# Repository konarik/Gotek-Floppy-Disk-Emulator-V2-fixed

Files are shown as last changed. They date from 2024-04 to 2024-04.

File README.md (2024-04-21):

Fixed PCB from original [Gotek-Floppy-Disk-Emulator-V2](https://github.com/RichardRozehnal/Gotek-Floppy-Disk-Emulator-V2):
* Add PCB edge cut for IDC 34-pin cable keying
* Change Buzzer type from Active to Passive (single click on drive motor step)
* Change "Buzzer_12x9.5RM7.6" footprint to "Buzzer_12x9.5RM6.5"

New modifications in V2.1:
* SMD Crystal
* 2nd SMD diode
* electrolytic capacitor replaced with 10uF MLCC
* decoupling capacitors moved close to the MCU
* added mounting holes
* generated production files for JLCPCB except through hole parts and 8bit SMD switch

# Gotek Floppy Disk Emulator V2

Gotek Floppy Disk Emulator V2

Emulátor disketové mechaniky starých počítačů a různých zařízení. Software se do počítače nahrává z obrazu originálního disku (např. ADF pro Amigu), který je uložen na USB flash disku. Tato verze hardwaru využívá firmware [FlashFloppy](https://github.com/keirf/FlashFloppy/wiki), který přidává spoustu nových funkcí a vylepšení oproti standardnímu Goteku. Na uvedém odkazu tvůrce, najdete detailní popisy všech funkcí a nastavení a také nejnovější firmware.

## Seznam součástek

| **Reference** | **Value** | **Qty**  |
| --- | --- | :----: |
| <sup>BZ1 </sup>| <sup>5V Passive Buzzer 12mm </sup>| <sup> 1 </sup> |
| <sup>C1,C2,C4,C7,C8,C9,C10,C12 </sup>| <sup>100nF </sup>| <sup> 8 </sup> |
| <sup>C3,C11 </sup>| <sup>10uF </sup>| <sup> 2 </sup> |
| <sup>C5,C6 </sup>| <sup>22pF </sup>| <sup> 2 </sup> |
| <sup>C13 </sup>| <sup>10uF/16V </sup>| <sup> 1 </sup> |
| <sup>D1,D101 </sup>| <sup>LED Green </sup>| <sup> 2 </sup> |
| <sup>D2 </sup>| <sup>1N4148 </sup>| <sup> 1 </sup> |
| <sup>H1 </sup>| <sup>Hole1 </sup>| <sup> 1 </sup> |
| <sup>H2 </sup>| <sup>Hole2 </sup>| <sup> 1 </sup> |
| <sup>H3 </sup>| <sup>Hole3 </sup>| <sup> 1 </sup> |
| <sup>H4 </sup>| <sup>Hole4 </sup>| <sup> 1 </sup> |
| <sup>J1 </sup>| <sup>Power Connector </sup>| <sup> 1 </sup> |
| <sup>J2 </sup>| <sup>OLED Display 0.91" Modul </sup>| <sup> 1 </sup> |
| <sup>J3 </sup>| <sup>USB_A </sup>| <sup> 1 </sup> |
| <sup>J5 </sup>| <sup>Programming Connector </sup>| <sup> 1 </sup> |
| <sup>J6 </sup>| <sup>Floppy Data Connector </sup>| <sup> 1 </sup> |
| <sup>Q1 </sup>| <sup>MMBT2222 </sup>| <sup> 1 </sup> |
| <sup>Q2,Q3,Q4,Q5,Q6,Q7 </sup>| <sup>BSS123 </sup>| <sup> 6 </sup> |
| <sup>R1 </sup>| <sup>4K7 </sup>| <sup> 1 </sup> |
| <sup>R2,R3,R7,R8,R9,R10,R11,R12,R13,R14,R15,R16,R17,R18,R19,R20,R21,R22,R23,R24,R25,R26,R101,R102 </sup> | <sup>1K </sup> | <sup>24 </sup> |
| <sup>R4,R27 </sup>| <sup>10K </sup> | <sup> 2 </sup> |
| <sup>R5,R6 </sup>| <sup>22R </sup> | <sup> 2 </sup> |
| <sup>SW1 </sup>| <sup>KY040 Rotary Encoder </sup> | <sup> 1 </sup> |
| <sup>SW2 </sup>| <sup>DIP Switch </sup> | <sup> 1 </sup> |
| <sup>U1 </sup>| <sup>AMS1117-3.3 </sup> | <sup> 1 </sup> |
| <sup>U2 </sup>| <sup>STM32F105RBTx </sup> | <sup> 1 </sup> |
| <sup>U3 </sup>| <sup>STMPS2141 </sup> | <sup> 1 </sup> |
| <sup>U4 </sup>| <sup>74HCT04 </sup> | <sup> 1 </sup> |
| <sup>Y1 </sup>| <sup>8MHz </sup> | <sup> 1 </sup> |

## Oživení

### Programování mikrokontroléru pomocí ST-Link V2

1. stáhněte si a nainstalujte flashovací program STM32-ST-Link Utility na webu [st.com](https://www.st.com/en/development-tools/stsw-link004.html).
2. propojte ST-Link V2 a Gotek V2 vývody SWCLK, SWDIO, GND a +3.3V
3. připojte ST-Link V2 k PC a spusťte flashovací program
4. připojte se na MCU přes menu Target/Connect
5. přes menu File/Open File vyberte soubor FF_Gotek-v3.20.hex (nebo jiný, který chcete nahrát do MCU)
6. spusťte flashování přes menu Target/Program & Verify a Start

### Nastavení DIP přepínače SW2

Pro Amigu, Atari ST a další počítače je nastavení:

| **sig** | **zap/vyp** | **funkce** |
| :-----: | :---: | --- |
| DC1 | OFF | |
| DC2 | ON | |
| J5 | OFF | |
| JC | OFF | |
| JB | ON | zapnutí/vypnutí emulace zvuku mechaniky |
| S0 | ON | |
| S1 | OFF | |

### Příprava USB flash disku a základní operace

1. USB flash disk naformátujte na FAT32 a nahrajte na něj obrazy disků, které budete chtít spouštět, např. ADF pro Amigu
2. připojte Gotek V2 s vloženým USB flash diskem k Amize (místo interního floppy disku), napájecí konektor je dobré před zapojením změřit, abyste do Goteku V2 nepustili 12V místo 5V, kvůli obrácení konektoru!
3. zapněte Amigu, na displeji se zobrazí první z podporovaných souborů, které jste nahráli a rotačním enkodérem mezi nima vybíráte
4. když najedete na soubor a počkáte 2s, tak se automaticky spustí (vloží do floppy mechaniky). Toto je možné v nastavení změnit, aby se automaticky nespouštěl. Potom bude pro vložení do mechaniky nutné stisknout rotační enkodér.
5. pokud chcete změnit orientaci posuvu v souborech (otáčení enkodéru doprava/doleva posouvat soubory nahoru/dolů), je to možné změnit v nastavení.
6. pokud se výběr souborů posune o jednu položku až při dvou nebo čtyřech krocích otočení enkodérem, je možné toto také upravit v nastavení

### Nastavení firmware

1. Gotek V2 funguje s defaultním nastavením i bez konfiguračního souboru
2. pokud však chcete určitou konfiguci změnit, vytvořte na USB flash disku adresář FF a do něj nahrajte konfigurační soubor FF.CFG
3. zrušení automatického spouštění souboru: autoselect-file-secs = 0
4. zrušení automatického vybrání adresáře: autoselect-folder-secs = 0
5. změna orientace posuvu v souborech: rotary = reverse
6. změna kroků enkodéru: rotary = half
7. je možné vybrat i více nastavení najednou, např.: rotary = reverse,half

## Další fotky (vzorky, úprava na BOT straně již není potřeba)

Gotek_V2_PCB_Top
Gotek_V2_PCB_Bot
Gotek_V2_PCB_Bot_osazeny

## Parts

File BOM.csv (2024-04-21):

Reference | Value | Datasheet | Footprint | Qty | DNP
BZ1 | 5V Passive Buzzer 12mm | ~ | Gotek_Floppy_Disk_Emulator_V2:Buzzer_12x9.5RM6.5 | 1
C1,C2,C4,C7,C8,C9,C10,C12 | 100nF | ~ | Capacitor_SMD:C_1206_3216Metric | 8
C3,C11 | 10uF | ~ | Capacitor_SMD:C_1206_3216Metric | 2
C5,C6 | 22pF | ~ | Capacitor_SMD:C_0402_1005Metric | 2
C13 | 10uF/16V | ~ | Capacitor_SMD:C_1206_3216Metric | 1
D1,D101 | LED Green | ~ | -- mixed values -- | 2
D2 | 1N4148 | ~ | Diode_SMD:D_SOD-123 | 1
H1 | Hole1 | DNP | MountingHole:MountingHole_3.2mm_M3_Pad_Via | 1
H2 | Hole2 | DNP | MountingHole:MountingHole_3.2mm_M3_Pad_Via | 1
H3 | Hole3 | DNP | MountingHole:MountingHole_3.2mm_M3_Pad_Via | 1
H4 | Hole4 | DNP | MountingHole:MountingHole_3.2mm_M3_Pad_Via | 1
J1 | Power Connector | ~ | Gotek_Floppy_Disk_Emulator_V2:PinHeader_1x04_P2.54mm_Horizontal | 1
J2 | OLED Display 0.91" Module | ~ | Gotek_Floppy_Disk_Emulator_V2:OLED_Display_0.91_Module | 1
J3 | USB_A | ~ | Gotek_Floppy_Disk_Emulator_V2:USB_A_Stewart_SS-52100-001_Horizontal | 1
J5 | Programming Connector | ~ | Connector_PinHeader_2.54mm:PinHeader_2x05_P2.54mm_Vertical | 1
J6 | Floppy Data Connector | ~ | Gotek_Floppy_Disk_Emulator_V2:PinHeader_2x17_P2.54mm_Horizontal | 1
Q1 | MMBT2222 | ~ | Package_TO_SOT_SMD:SOT-23 | 1
Q2,Q3,Q4,Q5,Q6,Q7 | BSS123 | http://www.diodes.com/assets/Datasheets/ds30366.pdf | Package_TO_SOT_SMD:SOT-23 | 6
R1 | 4K7 | ~ | Resistor_SMD:R_1206_3216Metric | 1
R2,R3,R7,R8,R9,R10,R11,R12,R13,R14,R15,R16,R17,R18,R19,R20,R21,R22,R23,R24,R25,R26,R101,R102 | 1K | ~ | Resistor_SMD:R_1206_3216Metric | 24
R4,R27 | 10K | ~ | Resistor_SMD:R_1206_3216Metric | 2
R5,R6 | 22R | ~ | Resistor_SMD:R_1206_3216Metric | 2
SW1 | KY040 Rotary Encoder | ~ | Connector_PinHeader_2.54mm:PinHeader_1x05_P2.54mm_Vertical | 1
SW2 | DIP Switch | ~ | Button_Switch_SMD:SW_DIP_SPSTx08_Slide_6.7x21.88mm_W8.61mm_P2.54mm_LowProfile | 1
U1 | AMS1117-3.3 | http://www.advanced-monolithic.com/pdf/ds1117.pdf | Package_TO_SOT_SMD:SOT-223-3_TabPin2 | 1
U2 | STM32F105RBTx | http://www.st.com/st-web-ui/static/active/en/resource/technical/document/datasheet/CD00220364.pdf | Gotek_Floppy_Disk_Emulator_V2:LQFP-64_10x10mm_P0.5mm | 1
U3 | STMPS2141 |  | Package_TO_SOT_SMD:SOT-23-5 | 1
U4 | 74HCT04 | https://assets.nexperia.com/documents/data-sheet/74HC_HCT04.pdf | Package_SO:SOIC-14_3.9x8.7mm_P1.27mm | 1
Y1 | 8MHz | ~ | Crystal:Crystal_SMD_5032-2Pin_5.0x3.2mm | 1

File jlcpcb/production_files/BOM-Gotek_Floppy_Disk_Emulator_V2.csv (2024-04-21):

Comment | Designator | Footprint | LCSC
USB_A | J3 | USB_A_Stewart_SS-52100-001_Horizontal | C112456
8MHz | Y1 | Crystal_SMD_5032-2Pin_5.0x3.2mm | C115962
10uF | C11,C13,C3 | C_1206_3216Metric | C13585
22pF | C5,C6 | C_0402_1005Metric | C1555
10K | R27,R4 | R_1206_3216Metric | C17902
4K7 | R1 | R_1206_3216Metric | C17936
22R | R5,R6 | R_1206_3216Metric | C17958
LED Green | D101 | LED_0805_2012Metric | C2297
100nF | C1,C10,C12,C2,C4,C7,C8,C9 | C_1206_3216Metric | C24497
1K | R10,R101,R102,R11,R12,R13,R14,R15,R16,R17,R18,R19,R2,R20,R21,R22,R23,R24,R25,R26,R3,R7,R8,R9 | R_1206_3216Metric | C4410
STMPS2141 | U3 | SOT-23-5 | C54624
AMS1117-3.3 | U1 | SOT-223-3_TabPin2 | C6186
74HCT04 | U4 | SOIC-14_3.9x8.7mm_P1.27mm | C672096
1N4148 | D2 | D_SOD-123 | C81598
STM32F105RBTx | U2 | LQFP-64_10x10mm_P0.5mm | C8349
MMBT2222 | Q1 | SOT-23 | C8512
BSS123 | Q2,Q3,Q4,Q5,Q6,Q7 | SOT-23 | C8545
DIP Switch | SW2 | SW_DIP_SPSTx08_Slide_6.7x21.88mm_W8.61mm_P2.54mm_LowProfile | C976370
5V Passive Buzzer 12mm | BZ1 | Buzzer_12x9.5RM6.5
Programming Connector | J5 | PinHeader_2x05_P2.54mm_Vertical
Power Connector | J1 | PinHeader_1x04_P2.54mm_Horizontal
Floppy Data Connector | J6 | PinHeader_2x17_P2.54mm_Horizontal
LED Green | D1 | LED_D3.0mm
OLED Display 0.91" Module | J2 | OLED_Display_0.91_Module
KY040 Rotary Encoder | SW1 | PinHeader_1x05_P2.54mm_Vertical
Hole4 | H4 | MountingHole_3.2mm_M3_Pad_Via
Hole3 | H3 | MountingHole_3.2mm_M3_Pad_Via
Hole2 | H2 | MountingHole_3.2mm_M3_Pad_Via
Hole1 | H1 | MountingHole_3.2mm_M3_Pad_Via

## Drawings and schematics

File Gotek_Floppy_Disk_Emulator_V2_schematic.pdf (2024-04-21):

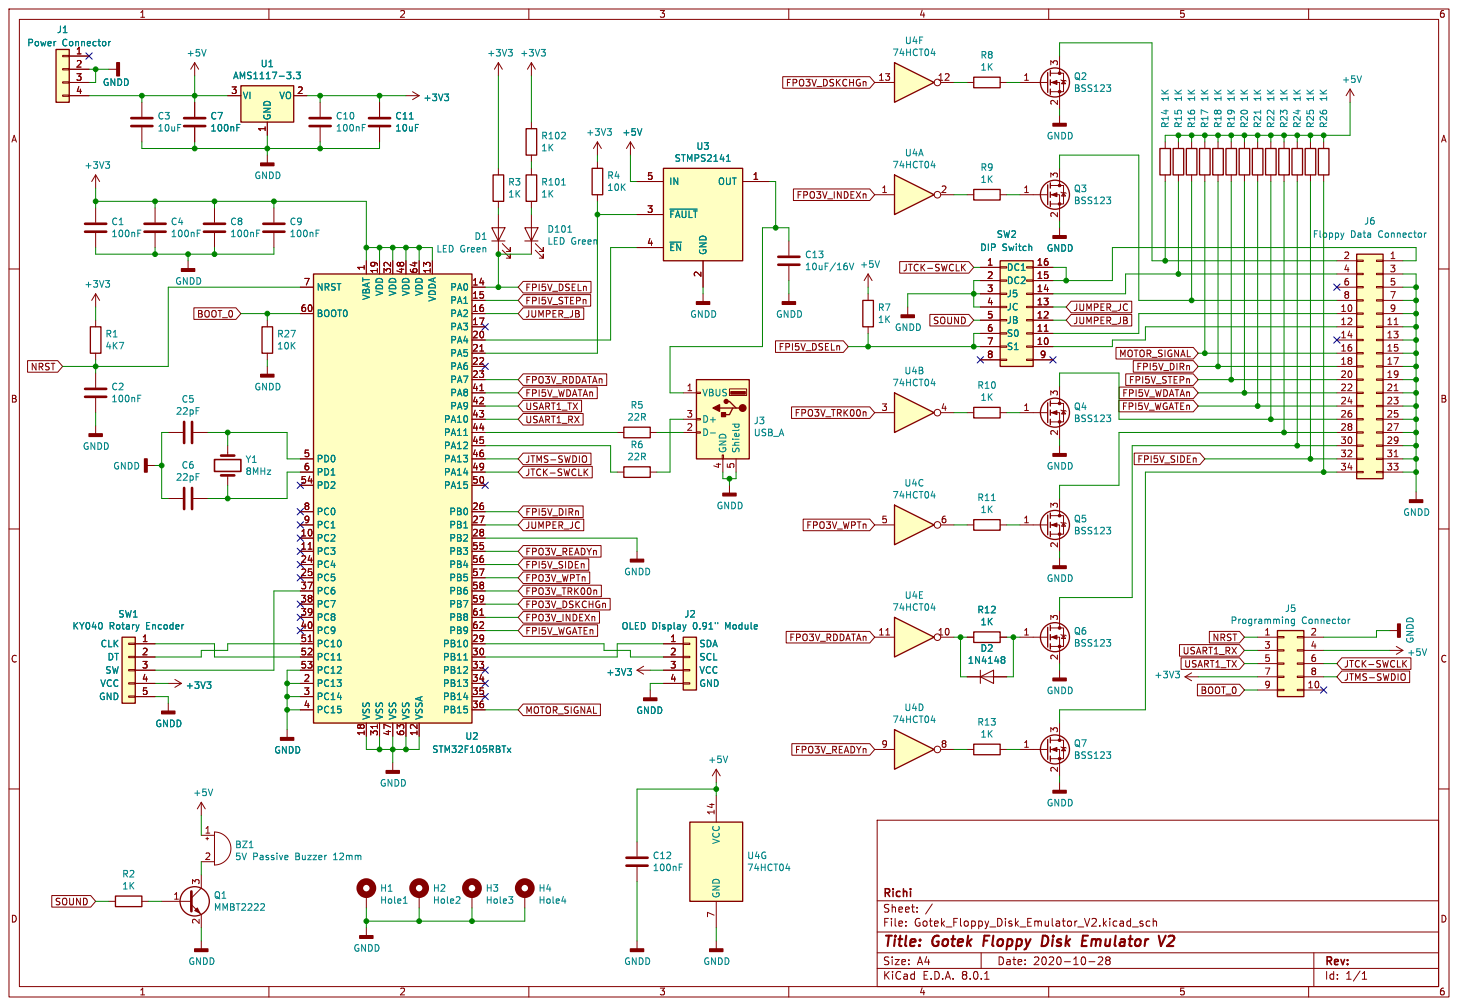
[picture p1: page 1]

2 3 Q2 BSS123 SDA 1 SCL 2 VCC 3 GND 4

1 PC2 10 PC3 11 VSSA 12 VDDA 13 PA0 14 PA1 15 PA2 16 PA3 17 VSS 18 VDD 19 PC13 2 PA4 20 PA5 21 PA6 22 PA7 23 PC4 24 PC5 25 PB0 26 PB1 27 PB2 28 PB10 29 PC14 3 PB11 30 VSS 31 VDD 32 PB12 33 PB13 34 PB14 35 PB15 36 PC6 37 PC7 38 PC8 39 PC15 4 PC9 40 PA8 41 PA9 42 PA10 43 PA11 44 PA12 45 PA13 46 VSS 47 VDD 48 PA14 49 PD0 5 PA15 50 PC10 51 PC11 52 PC12 53 PD2 54 PB3 55 PB4 56 PB5 57 PB6 58 PB7 59 PD1 6 BOOT0 60 PB8 61 PB9 62 VSS 63 VDD 64 NRST 7 PC0 8 PC1 9 U2 STM32F105RBTx C2
8MHz +3V3R1

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

Id: 1/1 Title: Gotek Floppy Disk Emulator V2

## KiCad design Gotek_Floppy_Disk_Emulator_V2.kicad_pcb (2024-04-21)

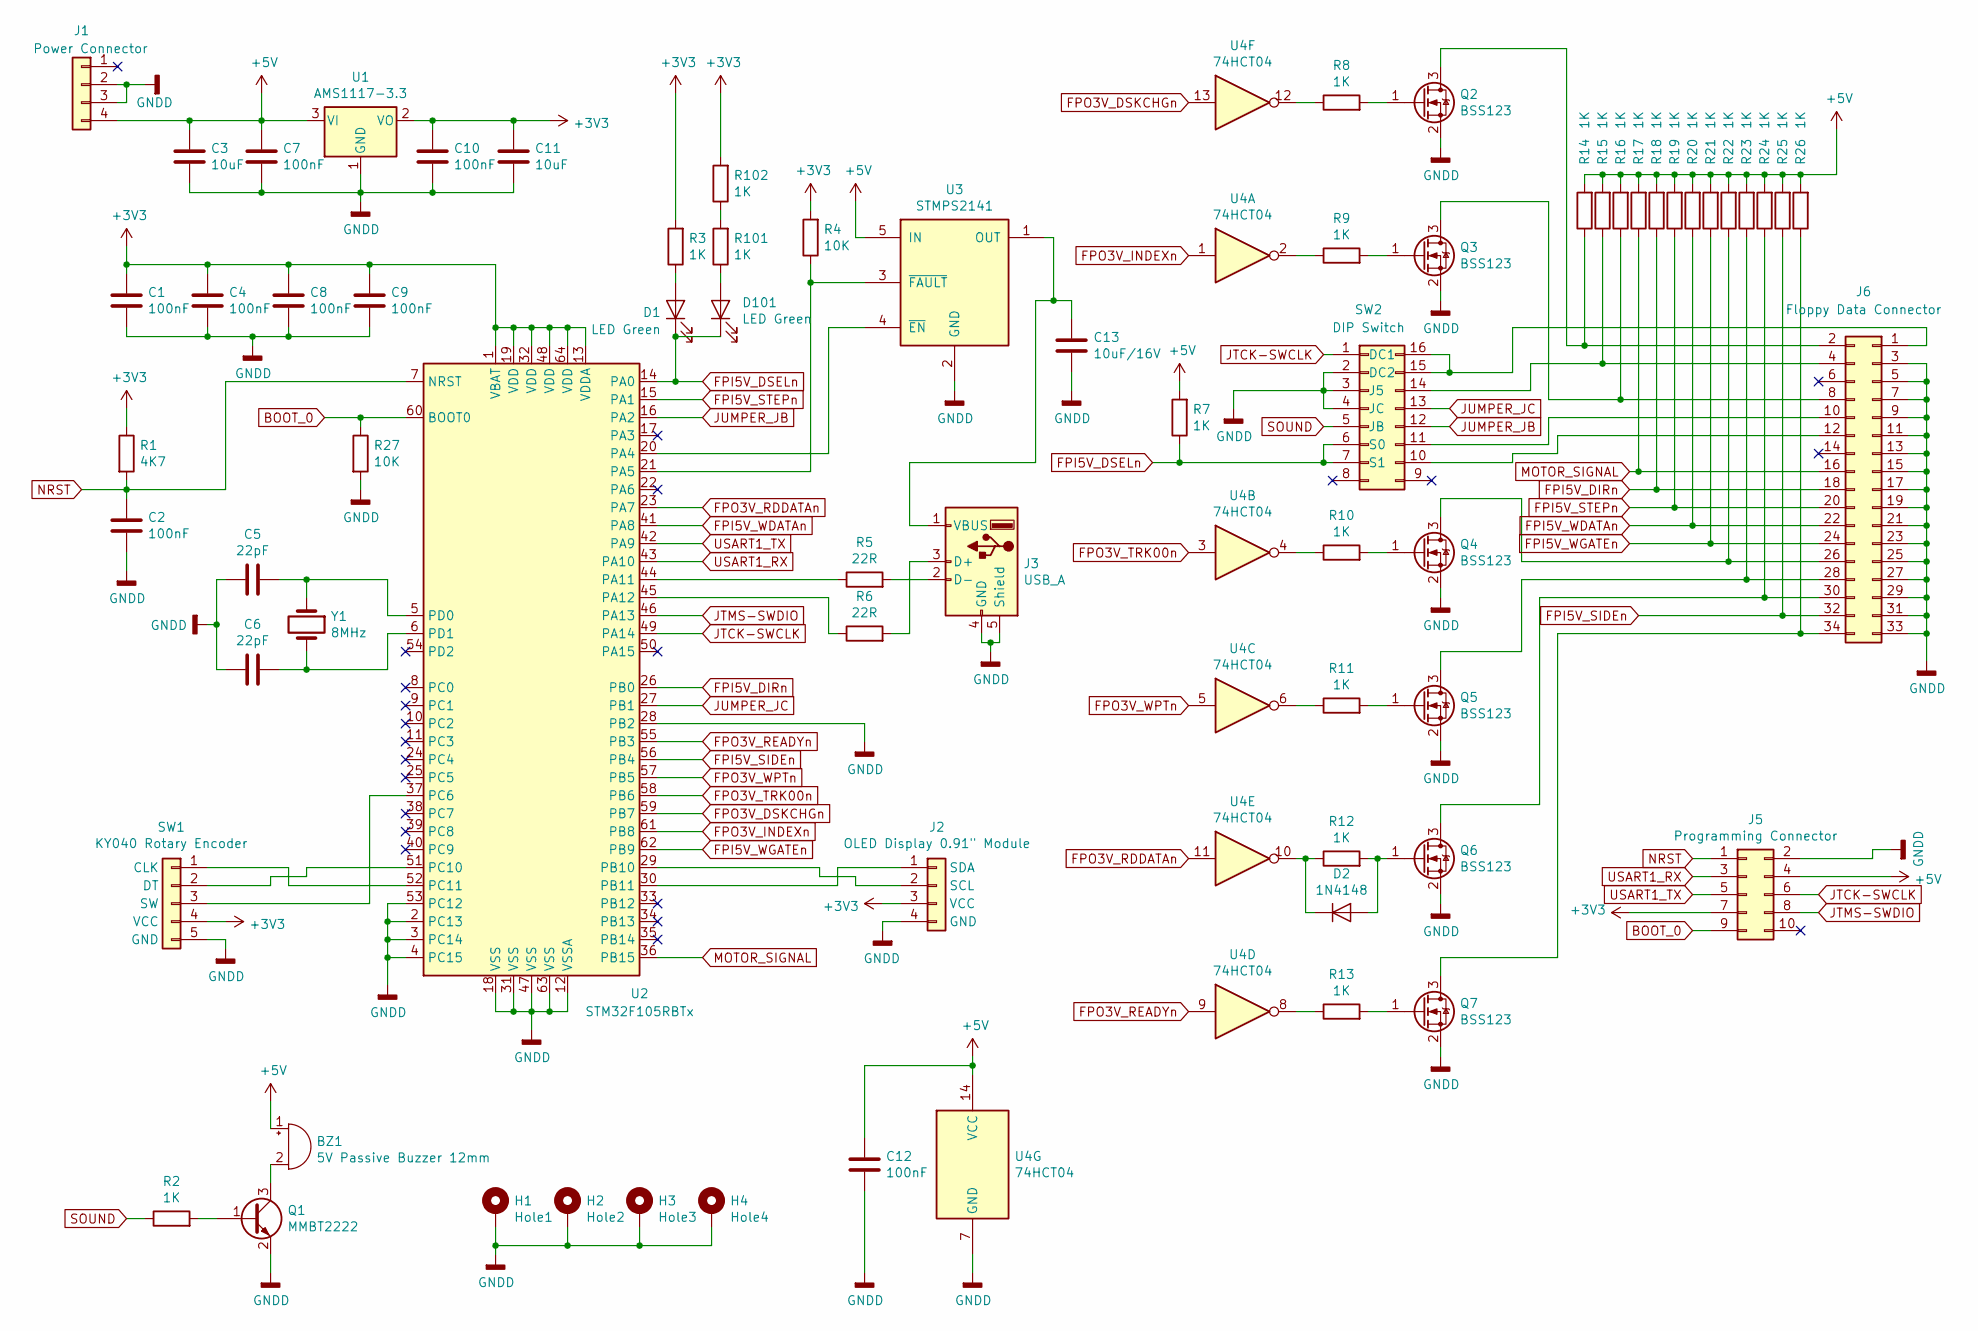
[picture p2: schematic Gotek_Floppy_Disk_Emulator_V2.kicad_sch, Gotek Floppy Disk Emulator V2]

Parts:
BZ1: 5V Passive Buzzer 12mm; Buzzer_12x9.5RM6.5
C1, C2, C4, C7, C8, C9, C10, C12: 100nF; C_1206_3216Metric
C3, C11: 10uF; C_1206_3216Metric
C5, C6: 22pF; C_0402_1005Metric
C13: 10uF/16V; C_1206_3216Metric
D1: LED Green; LED_D3.0mm
D2: 1N4148; D_SOD-123
D101: LED Green; LED_0805_2012Metric
H1: Hole1; MountingHole_3.2mm_M3_Pad_Via; Manufacturer_Part_Number DNP; LCSC DNP
H2: Hole2; MountingHole_3.2mm_M3_Pad_Via; Manufacturer_Part_Number DNP; LCSC DNP
H3: Hole3; MountingHole_3.2mm_M3_Pad_Via; Manufacturer_Part_Number DNP; LCSC DNP
H4: Hole4; MountingHole_3.2mm_M3_Pad_Via; Manufacturer_Part_Number DNP; LCSC DNP
J1: Power Connector; PinHeader_1x04_P2.54mm_Horizontal
J2: OLED Display 0.91" Module; OLED_Display_0.91_Module
J3: USB_A; USB_A_Stewart_SS-52100-001_Horizontal
J5: Programming Connector; PinHeader_2x05_P2.54mm_Vertical
J6: Floppy Data Connector; PinHeader_2x17_P2.54mm_Horizontal
Q1: MMBT2222; SOT-23
Q2, Q3, Q4, Q5, Q6, Q7: BSS123; SOT-23
R1: 4K7; R_1206_3216Metric
R2, R3, R7, R8, R9, R10, R11, R12, R13, R14, R15, R16, R17, R18, R19, R20, R21, R22, R23, R24, R25, R26, R101, R102: 1K; R_1206_3216Metric
R4, R27: 10K; R_1206_3216Metric
R5, R6: 22R; R_1206_3216Metric
SW1: KY040 Rotary Encoder; PinHeader_1x05_P2.54mm_Vertical
SW2: DIP Switch; SW_DIP_SPSTx08_Slide_6.7x21.88mm_W8.61mm_P2.54mm_LowProfile
U1: AMS1117-3.3; SOT-223-3_TabPin2
U2: STM32F105RBTx; LQFP-64_10x10mm_P0.5mm
U3: STMPS2141; SOT-23-5
U4: 74HCT04; SOIC-14_3.9x8.7mm_P1.27mm
Y1: 8MHz; Crystal_SMD_5032-2Pin_5.0x3.2mm

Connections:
+3V3: C1.1, C4.1, C8.1, C9.1, C10.1, C11.1, J2.3 (VCC), J5.7, R1.1, R3.2, R4.2, R102.2, SW1.4 (VCC), U1.2 (VO), U2.1 (VBAT), U2.13 (VDDA), U2.19 (VDD), U2.32 (VDD), U2.48 (VDD), U2.64 (VDD)
+5V: BZ1.1 (-), C3.1, C7.1, C12.1, J1.4, J5.4, R7.2, R14.2, R15.2, R16.2, R17.2, R18.2, R19.2, R20.2, R21.2, R22.2, R23.2, R24.2, R25.2, R26.2, U1.3 (VI), U3.5 (IN), U4.14 (VCC)
BOOT_0: J5.9, R27.1, U2.60 (BOOT0)
FPI5V_DIRn: J6.18, R18.1, U2.26 (PB0)
FPI5V_DSELn: D1.1 (K), D101.1 (K), R7.1, SW2.6 (S0), SW2.7 (S1), U2.14 (PA0)
FPI5V_SIDEn: J6.32, R25.1, U2.56 (PB4)
FPI5V_STEPn: J6.20, R19.1, U2.15 (PA1)
FPI5V_WDATAn: J6.22, R20.1, U2.41 (PA8)
FPI5V_WGATEn: J6.24, R21.1, U2.62 (PB9)
FPO3V_DSKCHGn: U2.59 (PB7), U4.13
FPO3V_INDEXn: U2.61 (PB8), U4.1
FPO3V_RDDATAn: U2.23 (PA7), U4.11
FPO3V_READYn: U2.55 (PB3), U4.9
FPO3V_TRK00n: U2.58 (PB6), U4.3
FPO3V_WPTn: U2.57 (PB5), U4.5
GNDD: C1.2, C2.2, C3.2, C4.2, C5.2, C6.2, C7.2, C8.2, C9.2, C10.2, C11.2, C12.2, C13.2, H1.1, H2.1, H3.1, H4.1, J1.2, J1.3, J2.4 (GND), J3.4 (GND), J3.5 (Shield), J5.2, J6.3, J6.5, J6.7, J6.9, J6.11, J6.13, J6.15, J6.17, J6.19, J6.21, J6.23, J6.25, J6.27, J6.29, J6.31, J6.33, Q1.2 (E), Q2.2 (S), Q3.2 (S), Q4.2 (S), Q5.2 (S), Q6.2 (S), Q7.2 (S), R27.2, SW1.5 (GND), SW2.2 (DC2), SW2.3 (J5), SW2.4 (JC), U1.1 (GND), U2.2 (PC13), U2.3 (PC14), U2.4 (PC15), U2.12 (VSSA), U2.18 (VSS), U2.28 (PB2), U2.31 (VSS), U2.47 (VSS), U2.53 (PC12), U2.63 (VSS), U3.2 (GND), U4.7 (GND)
JTCK-SWCLK: J5.6, SW2.1 (DC1), U2.49 (PA14)
JTMS-SWDIO: J5.8, U2.46 (PA13)
JUMPER_JB: SW2.12, U2.16 (PA2)
JUMPER_JC: SW2.13, U2.27 (PB1)
MOTOR_SIGNAL: J6.16, R17.1, U2.36 (PB15)
NRST: C2.1, J5.1, R1.2, U2.7 (NRST)
unnamed: BZ1.2 (+), Q1.3 (C)
unnamed: D1.2 (A), R3.1
unnamed: D2.2 (A), Q6.1 (G), R12.2
unnamed: D2.1 (K), R12.1, U4.10
unnamed: D101.2 (A), R101.1
unnamed: J2.2 (SCL), U2.29 (PB10)
unnamed: J2.1 (SDA), U2.30 (PB11)
unnamed: J3.3 (D+), R6.2
unnamed: J3.2 (D-), R5.2
unnamed: C13.1, J3.1 (VBUS), U3.1 (OUT)
unnamed: J6.1, SW2.15, SW2.16
unnamed: J6.2, Q2.3 (D), R14.1
unnamed: J6.4, R15.1, SW2.14
unnamed: J6.8, Q3.3 (D), R16.1
unnamed: J6.10, SW2.11
unnamed: J6.12, SW2.10
unnamed: J6.26, Q4.3 (D), R22.1
unnamed: J6.28, Q5.3 (D), R23.1
unnamed: J6.30, Q6.3 (D), R24.1
unnamed: J6.34, Q7.3 (D), R26.1
unnamed: Q1.1 (B), R2.2
unnamed: Q2.1 (G), R8.2
unnamed: Q3.1 (G), R9.2
unnamed: Q4.1 (G), R10.2
unnamed: Q5.1 (G), R11.2
unnamed: Q7.1 (G), R13.2
unnamed: R8.1, U4.12
unnamed: R9.1, U4.2
unnamed: R10.1, U4.4
unnamed: R11.1, U4.6
unnamed: R13.1, U4.8
unnamed: R101.2, R102.1
unnamed: SW1.1 (CLK), U2.52 (PC11)
unnamed: SW1.2 (DT), U2.51 (PC10)
unnamed: SW1.3 (SW), U2.37 (PC6)
unnamed: U2.20 (PA4), U3.4 (~EN)
unnamed: R4.1, U2.21 (PA5), U3.3 (~FAULT)
unnamed: R5.1, U2.44 (PA11)
unnamed: R6.1, U2.45 (PA12)
unnamed: C5.1, U2.5 (PD0), Y1.1
unnamed: C6.1, U2.6 (PD1), Y1.2
SOUND: R2.1, SW2.5 (JB)
USART1_RX: J5.3, U2.43 (PA10)
USART1_TX: J5.5, U2.42 (PA9)

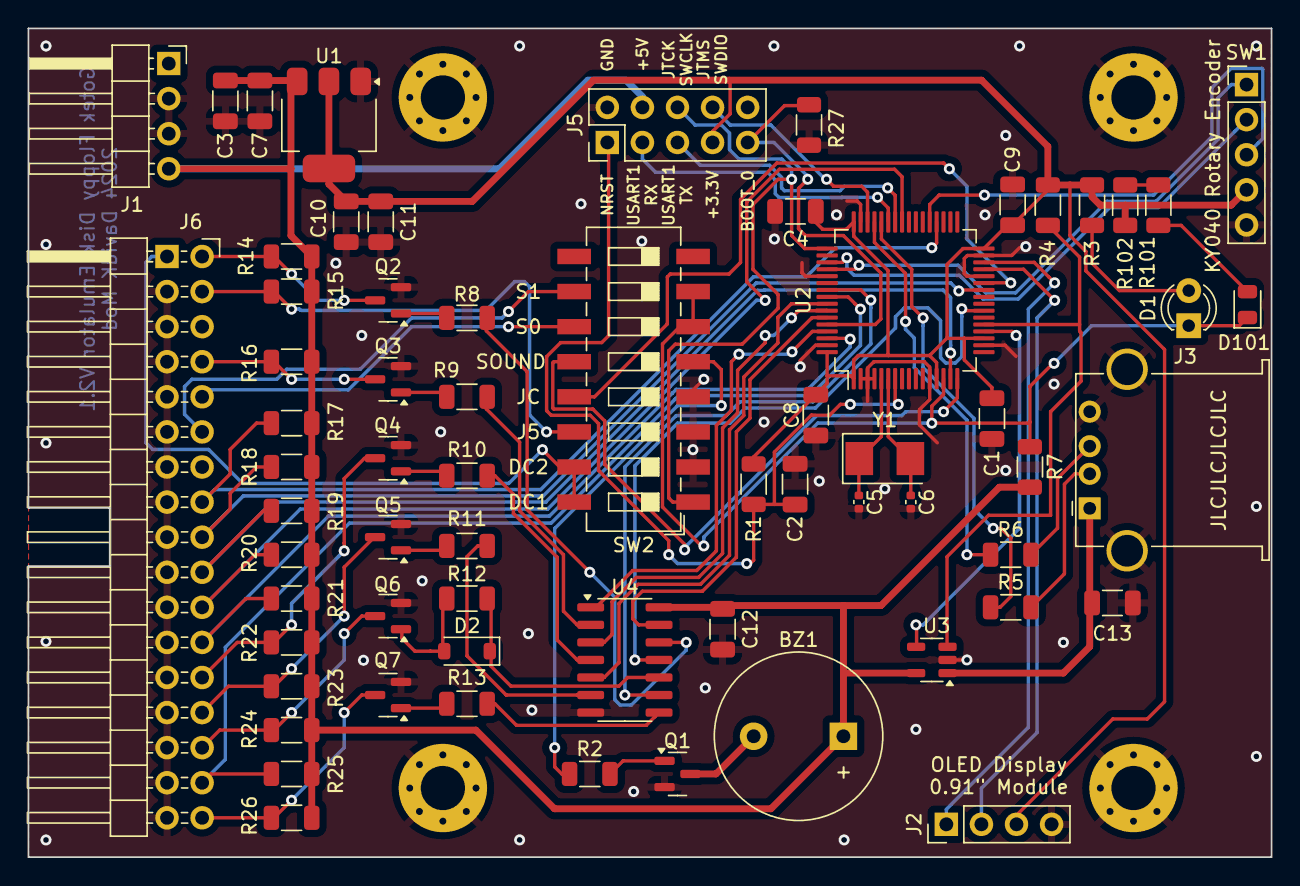
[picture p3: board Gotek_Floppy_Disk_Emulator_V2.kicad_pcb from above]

Board: 2 copper layers, 90.0 x 60.0 mm, 69 parts (0 on the bottom side), 66 nets.

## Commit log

2024-04-19 Updated to KiCAD version 6
    [Gotek_Floppy_Disk_Emulator_V2.kicad_pcb, Gotek_Floppy_Disk_Emulator_V2.kicad_sch]
2024-04-19 KiCAD v8 version
    [Gotek_Floppy_Disk_Emulator_V2.kicad_pcb, Gotek_Floppy_Disk_Emulator_V2.kicad_sch]
2024-04-19 Production files generated
    Some parts were exchanged for SMD mounted. For production generation was used Bouni/kicad-jlcpcb-tools plugin.
    [BOM-Gotek_Floppy_Disk_Emulator_V2.csv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]
2024-04-19 Removed old KiCAD files
    [Gotek_Floppy_Disk_Emulator_V2.sch]
2024-04-19 Schematic updated
    [Gotek_Floppy_Disk_Emulator_V2 - BOM.ods]
2024-04-21 V2.1
    Production files for JLCPCB excluding through hole parts and 8bit switch. Capacitors moved close to the voltage input pins of the MCU.
    [BOM-Gotek_Floppy_Disk_Emulator_V2.csv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]
2024-04-21 Wider 5V patch for USB
    [CPL-Gotek_Floppy_Disk_Emulator_V2.csv, Gotek_Floppy_Disk_Emulator_V2-CuBottom.gbr, Gotek_Floppy_Disk_Emulator_V2-CuTop.gbr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]
2024-04-21 bom generated
    [BOM.csv, Gotek_Floppy_Disk_Emulator_V2.kicad_pcb]
